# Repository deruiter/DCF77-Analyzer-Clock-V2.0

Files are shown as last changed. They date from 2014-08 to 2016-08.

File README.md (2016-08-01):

 DCF77 Analyzer/Clock v2.0

 This sketch is free software; you can redistribute it and/or
 modify it under the terms of the GNU Lesser General Public
 License as published by the Free Software Foundation; either
 version 2.1 of the License, or (at your option) any later version.
 
 This sketch is distributed in the hope that it will be useful,
 but WITHOUT ANY WARRANTY; without even the implied warranty of
 MERCHANTABILITY or FITNESS FOR A PARTICULAR PURPOSE.  See the GNU
 Lesser General Public License for more details.
 
 You should have received a copy of the GNU Lesser General Public
 License along with this library; if not, write to the Free Software
 Foundation, Inc., 51 Franklin St, Fifth Floor, Boston, MA  02110-1301  USA

 This C++ code is far from optimized because I myself am an Arduino and C++ novice.
 But even after learning some more now, I want to keep the code simpel and readable.
 That is why I maybe over-documented the code to help understand what's going on.

 Erik de Ruiter
 2014-2016

 May 2014 First version
 March 2016 - big overhaul...
 July 2016 - Start with building the v2.0 Clock and adapting the sketch

 Version 2.0 - August 2016
 - This sketch is adapted for my 2.0 version of the DCF/Analyzer Clock. It used the Arduino MEGA and the DCF Superfilter
   by default and to drive the many seperate LED's I now use the ports of an Arduino Mega instead of a Maxim 7219 chip. 
   This is because driving LED's with many different Voltage/Current specs is problematic with the Maxim chip. 
   Lighting additional LED's for expample will influence (dim) the LED's already on. As I'm not an electronics engineer
   my only solution was to use the extra ports of the Arduino Mega. Ofcourse you can use transistors or extra chips to
   drive the LED's but for me this was the obvious solution.
 - Removed all the code to use Maxim 72xx chips with Common Anode displays

                                                                                                                                                                                                                                                                                                                                                                                                                                                                                                                                                                                                                                                                                                                                                                                                                                                                                                                                                                                                                                                                                                                                                                                                                                                                                                                                                                                                                                                                                                                                                                                                                                                                                                                                                                                                                                                                                                                                                                                                                                                                                                                                                                                                                                                                                                                                                                                                                                                                                                                                                                                                                                                                                                                                                                                                                                                                                                                                                                                                                                                                                                                                                                                                                                                                                                                                                                                                                                                                                                                                                                                                                                                                                                                                                            

 Version 1.72 - May 2016
 - Option: Use a cheap Ebay PIR detector to shut off selectable display's when no activity is detected. 
   The switch off delay can be set by the user to prevent the display shutting of if a person
   is not moving but the display should be on.
 - Now the display Night shut-down can be disabled by making both values 'POWERSAVINGOFFTIME'
   and 'POWERSAVINGONTIME' zero. 
 - Fixed temperature display not shutting off at powersave mode.  
 - errorCounter display did not reset every hour so that's fixed

 Version 1.71
 - User option to reset temperature min/max memory at midnight

 Version 1.7:
 - The resolution of the temperature display is improved: from 0.5 to 0.1 degrees Celsius
   Because of the time the DS18B20 sensor needs to convert the temperature and to keep the code clean, 
   the temperature display is updates once per minute.
 - Parity check routine optimized. 
 - More reliable check for bad DCF data, preventing RTC update with invalid data.
 - EoB error now clears inner LED ring as it should.
 - The DCF OK LED now displays the condition of the DCF signal more reliably. Turns off immediately if an error occurs
   and only turns ON when all 3 parity bits are OK.

 Version 1.6:
 - Changed temperature function to only calculate once per minute. Got strange errors before the change because
   I used a delay of 100ms to give the DS18B20 sensor time to calculate the temperature. But the delay function is
   a very bad idea in most c++ code so I finally got rid of it.

 Version 1.5:
 - Complete overhaul of the scanSignal function and the rest of the code! My first attempt worked but could be improved...
 - The rPW and rPT led's did not work as I intended so that is corrected now.
 - The End of Buffer error check routine does work now as it should.
 - I incorporated a Parity check of the incoming DCF signal. In the signal 3 Parity bits are sent so now these are
   checked and only if all three are OK, the received time information is accepted, the display is updated and the RTC synced.
   if desired, you can attach 3 extra dual-color LED's (Common Cathode) to see if each of the 3 Parity bits are OK or Failed.
 - I made wiring (or changing the wiring) much easier I think by putting all the PIN config in one easy to read table
 - As long as you use 1 DS18B20 temp. sensor, I edited the code so you no longer need to figure out the address of the I2C device.
 - Big clean-up of the code...
 - Powersaving by shutting off the displays (the clock remains functioning as normal)
   can now be configured somewhat easier by editing two variables POWERSAVINGONTIME and POWERSAVINGOFFTIME.
 - changed some variable names:
   - Maxim instances 'lc' and 'lc1' are now MaximCC and MaximCA
   - Display description MaximDcfTime is now DisplayTempWeek 
   - DCF77SOUNDPIN is now BUZZERSWITCHPIN
 - LED/Display test after power up now build in

  Short description:
   
  Power On:
    After power-on, first a LED test is performed. The LED's and displays lite up sequentially to keep the power consumption low.
    Then the clock starts receiving DCF pulses and when a Minute Mark (2 seconds gap) is detected, the Minute Marker LED is lit
    and the buffer counter is reset. The inner LED ring now will show the incoming DCF pulses which are also stored in the buffer.
    At 3 moments during reception of data the parity DCF bits are checked to see if the data is valid.

  Valid data received:
    When, at the end of the minute, after the Minute Mark is detected (BF (Buffer Full) LED is lit), all three parity bits are OK
    ('DCF OK' LED is lit), the buffer information is used to extract time and date information. 
    Then the RTC clock is updated ('RTC Synced' LED is lit) and the inner LED ring information is copied to the outer LED ring. 
    The time, date and week display, day LED, summer/wintertime and leap year LED information is updated with the new time information.

  No valid data:
    When one or more of the parity bits are not OK because of a noisy signal, receiving of DCF information is continued but
    will not be used to update the RTC, display's and LED's. The outer LED ring, 'RTC synced' and 'DCF OK' LED's will be reset. 
    Time, date, week, day LED, summer/wintertime LED and leap year LED are not affected and keep displaying the last received valid values.
    The 'Period Time' and/or 'Period With' error LED's will indicate the error(s) and the error counter display is updated. 
    Every hour, the error display will bet set to zero. 
    The EoB, End of Buffer LED is lit when more DCF pulses are received before the Minute Mark is detected due to a noisy signal.
    (When a minute Mark is detected we should have no more than 58 bits/pulses) 
    After the detection of the Minute Marker, a new cycle is started.
 
  Temperature:
    At the 30 second mark, the temperature display will show the High and Low values of the past period after the last reset.
  
  Chime:
    At the beginning of each hour, the Chime (if connected) will sound. 
    At night time, a time set by the user in the code itself, the chime is disabled.

  Power saving, two options:
    1. NIGHT SHUT OFF
       At times set by the user, the displays are shutt off at night and turned on in the morning.
       Look at the POWERSAVINGOFFTIME and POWERSAVINGONTIME variables. 
       Check the function <turnDisplaysOff> to select which displays you want to shut off at night.
    2. PIR SENSOR
       Connect a PIR sensor and activate the PIR option POWERSAVE_BY_PIR and the the delay at PIR_DELAY_TIME.
       Every time the PIR detector senses movement, a minute counter is reset but if no movement is detected
       longer than the PIR_DELAY_TIME, the displays are shut off. 
       When movement occurs, the displays immediately switch on. 
    Note: as said before, the clock will function normally while the displays are shut off. 
    The only thing is you can't see it... ;)

  DCF beep:
    With a switch, connected to pin BUZZERSWITCHPIN, you can hear the received DCF bits coming in. 
    The tone duration is equivalent to pulse width of the DCF bits, so either 100 or 200 ms.
  
  Miscelleanous:
    When the RTC battery is empty or a connection fault is detected, the RTC Error LED is lit.

 CREDITS:
 I learned a lot from the work of Matthias Dalheimer and Thijs Elenbaas who made their own DCF77 decoders.
 Without their work I would not have known where to start.
 I ended up writing my own code (using bits and pieces of their ideas) so I could understand what is happening...
 My code is far from efficient or advanced but it does work and I know what is going on.
 
 * A big Thank You to Brett Oliver and Joop Tap for pointing out some errors!

 Interesting websites:

 - Brett Oliver         : http://home.btconnect.com/brettoliver1/
 - Joop Tap             : http://www.jooptap.nl
 - Thijs Ellenbaas      : http://thijs.elenbaas.net/2012/04/arduino-dcf77-radio-clock-receiver-hardware-2/
 - Mathias Dalheimer    : https://github.com/roddi/DCF77-Arduino/blob/master/DCF77Servoclock/DCF77.h
 - DCF77 wikipedia      : https://en.wikipedia.org/wiki/DCF77
 - Much more DCF77 info : http://www.picbasic.nl/indexes_uk.htm

 - My Flickr website    : https://www.flickr.com/photos/edr1924/albums
 - My Github website    : https://github.com/deruiter
 - The Instructables website for this clock: soon!

 */

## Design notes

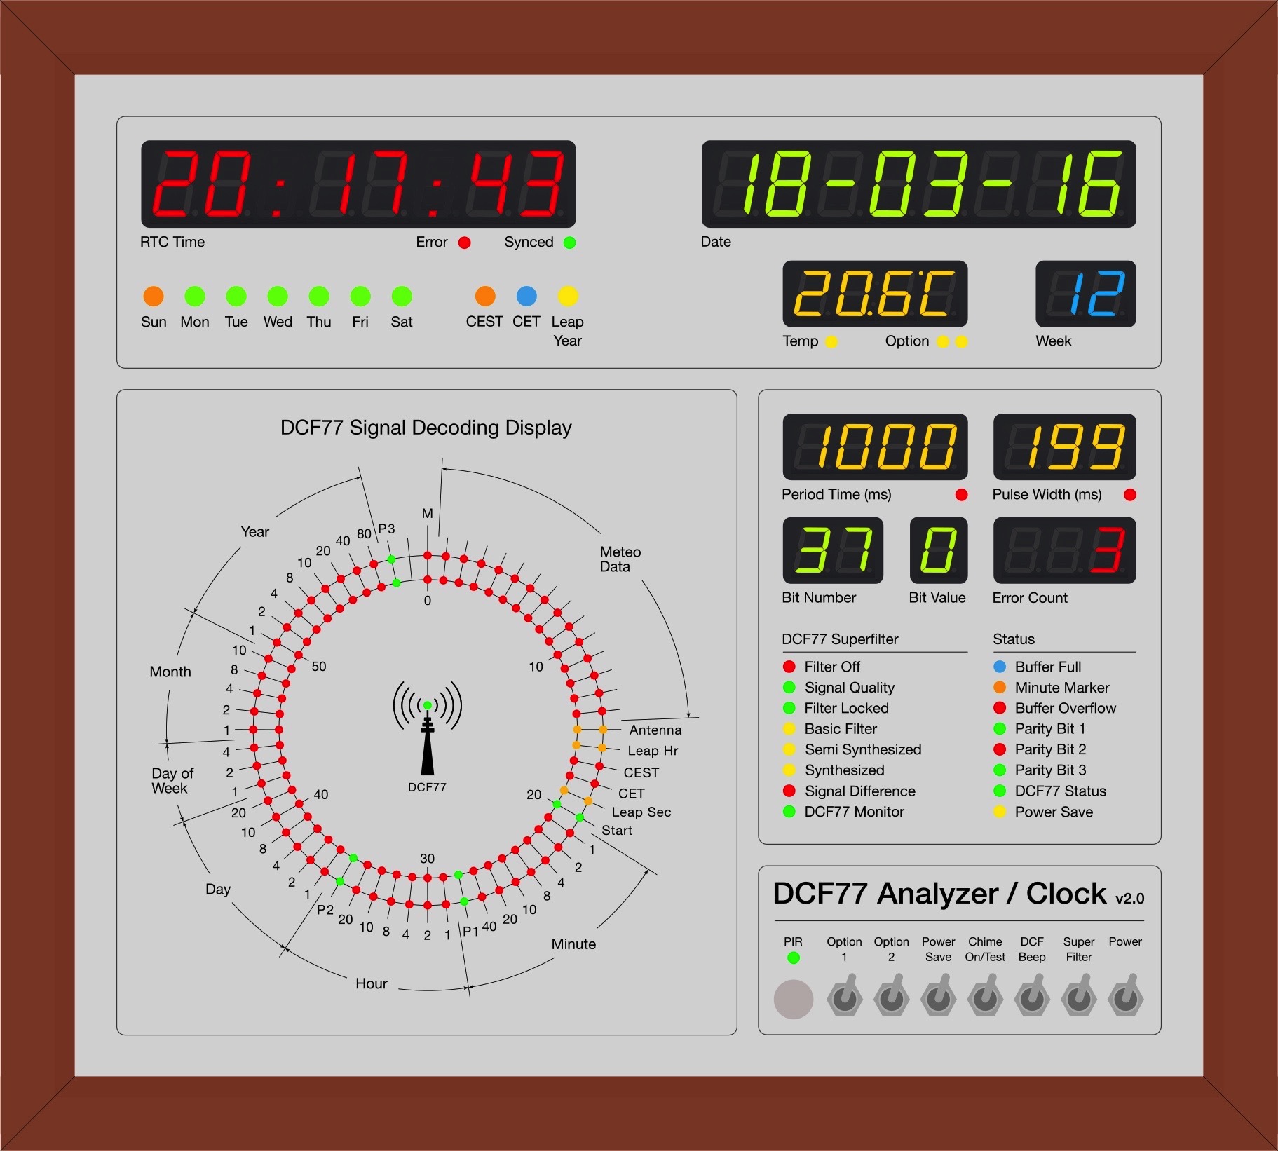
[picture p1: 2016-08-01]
DCF77_Analyzer_Clock_v2_FrontPanel_Preview.jpg

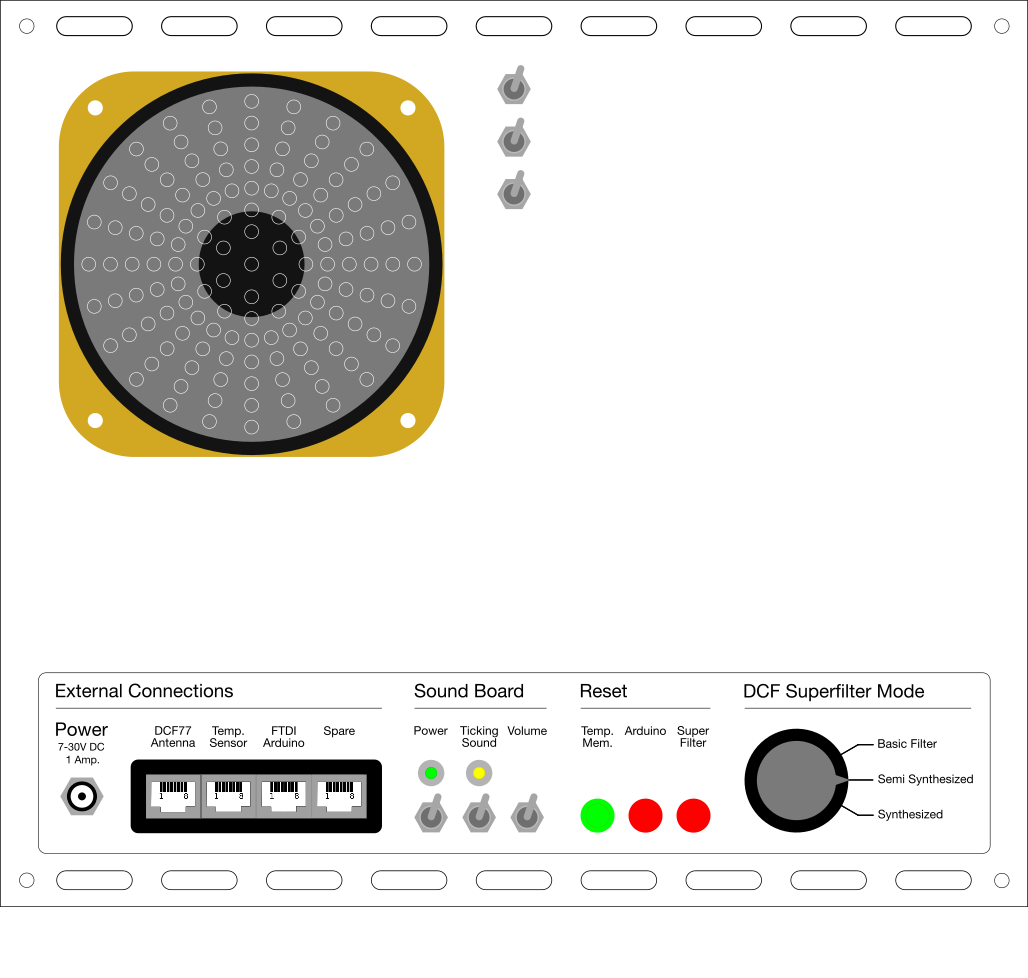
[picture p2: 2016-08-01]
DCF77_Analyzer_Clock_v2_BackPanel_Preview.png

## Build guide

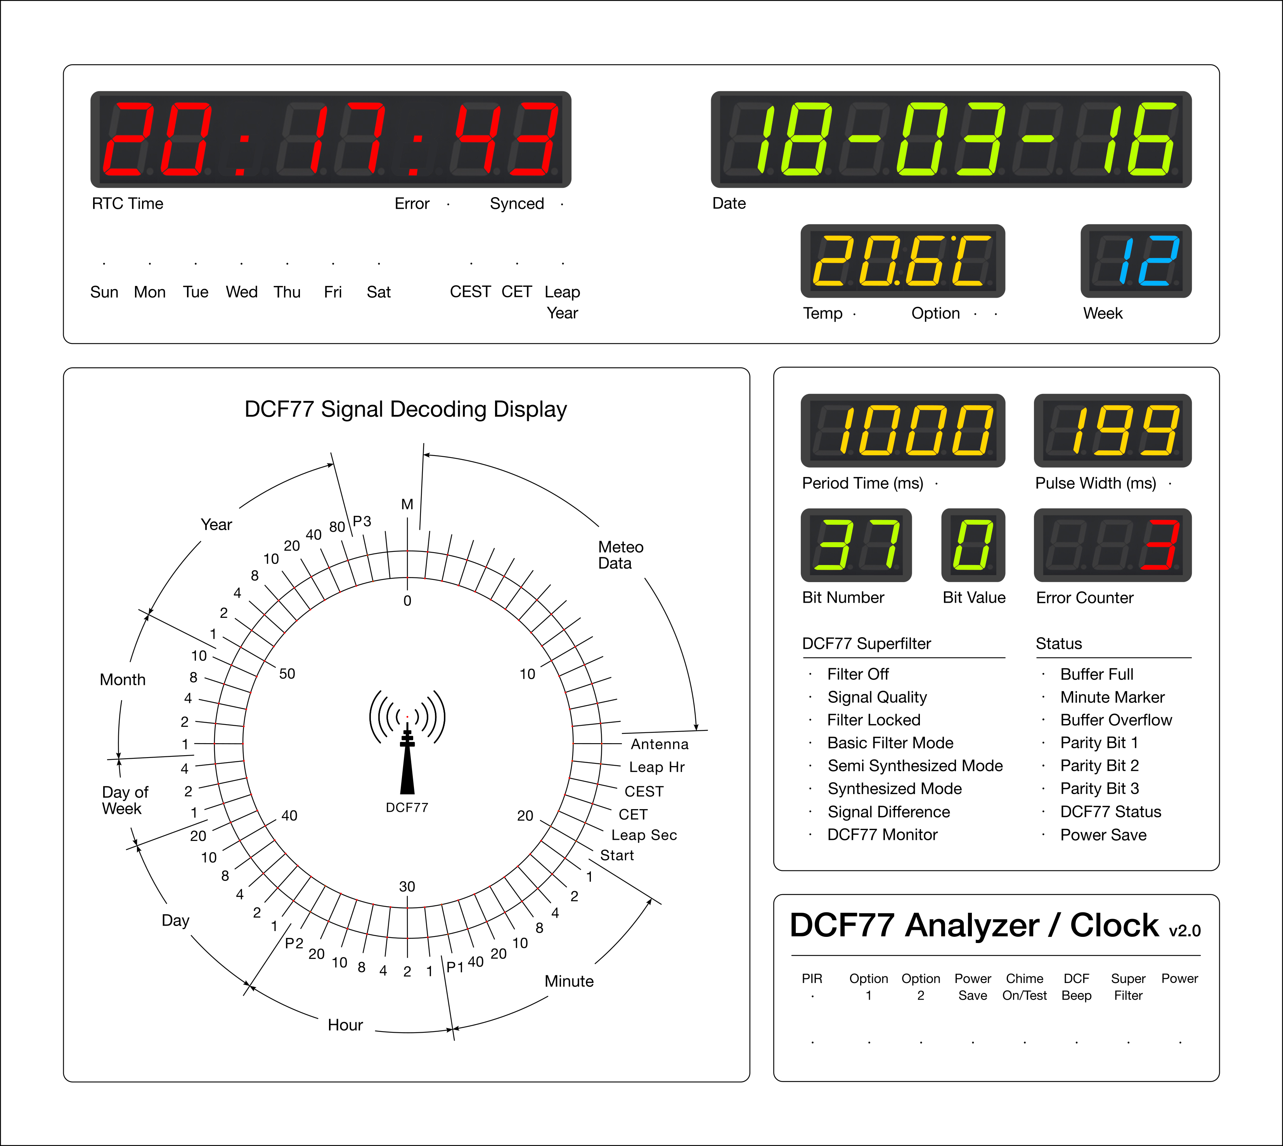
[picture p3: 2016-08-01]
Front_Panel_PrintService_Drawing/DCF77_Analyzer_Clock_v2_FrontPanel_ALUPRINT.jpg

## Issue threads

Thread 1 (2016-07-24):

dcf77 - analyzer - clock

adebruijn, 2016-07-24:
hello mr de ruiter, i am dutch too.

want to make your dcf77 a-clock. very impressive design.

before i start to buy everything by Conrad, is there a kit available ? If there is, it is  easier for me because i am a beginner. I have downloaded al the files. where can i find the code to program the ardueno ?

Greetings

André de Bruijn
Voorhout
The netherlands

deruiter, 2016-07-25:
Hello André, thanks for your interest in my clock.

No, I have no kit for the clock...

On the [Arduino website](http://forum.arduino.cc) you can find all the information you need to program the Arduino.
Reading your question, I think you are better off when you first familiarize yourself with the Arduino platform and the C++ programming language.
This DCF Clock project is not for beginners, I think, although I was myself a beginner when I made it.
BUT I spent hundreds of hours (a year) on the Arduino forum and searching the internet to solve ANY problem I encountered.
Be prepared to do a lot of study yourself, that is the only way to learn and it's very much worth it.

So buy an Arduino kit, and learn to program yourself first so you are able to understand the basics and then invest the money to make bigger projects. You will have a lot of fun learning and discovering the endless possibilities of the Arduino!

adebruijn, 2016-08-12:
hoi erik,

Nog een vraagje, heb jij de benodigde printplaatjes te koop ? ik zag een heel stapeltje op een van je foto's.

scheelt me een heleboel werk. ik kan zelf etsen en heb een uv lamp etc, maar als je ze op de plank hebt ?

groet

André de Bruijn

afmdebruijn@me.com

06-22569679

________________________________
Van: Erik <notifications@github.com>
Verzonden: maandag 25 juli 2016 09:03
Aan: deruiter/DCF77-Analyzer-Clock
CC: adebruijn; State change
Onderwerp: Re: [deruiter/DCF77-Analyzer-Clock] dcf77 - analyzer - clock (#1)

Closed #1<https://github.com/deruiter/DCF77-Analyzer-Clock/issues/1>.

-
You are receiving this because you modified the open/close state.
Reply to this email directly, view it on GitHub<https://github.com/deruiter/DCF77-Analyzer-Clock/issues/1#event-733251882>, or mute the thread<https://github.com/notifications/unsubscribe-auth/ATq4_enD-FUXVqHSL3DVndExIYXXLoBxks5qZHv1gaJpZM4JTlvi>.

deruiter, 2016-08-13:
Hello André,

I like to keep the conversation in English so everyone can understand what's going on.

No, sorry I have no spare PCB's left.
I think etching yourself is not an option in this case because my designs are double sided and the margins are very tiny.

I alway order my pcb's at iTead, and you have them delivered in 2-3 weeks.

Good luck with your build!

adebruijn, 2016-08-21:
hello,

what type of dcf antenna do you use ?

I use de one from conrad, but it does not give me a good signal.

if i run the superfilter program and looking at the serial monitor it seems to be to noisy.

greetings andre

brettoliver, 2016-08-21:
Hi I use this http://www.hkw-shop.de/Empfangstechnik-AM/Antenne-77-5kHz-10x100mm.html?listtype=search&searchparam=dcf77   There is a write up here on Udo's site https://blog.blinkenlight.net/experiments/dcf77/dcf77-receiver-modules/

adebruijn, 2016-09-10:
The 10cm ferriet is producing now a perfect signal.

mr de ruiter, i use the common cathode display's,
the type stated on your display prints. SC39 11 type

what do you mean with the line in your readme file:
Removed all the code to use Maxim 72xx chips with Common Anode displays

do i have to use te Common Anode ?

greetings

André

deruiter, 2016-09-10:
Hello André, Glad you have a good signal now!

In the Clock version 2.0 code, I do not use the [Sparkfun 4 digit display](https://www.sparkfun.com/products/9483) anymore. I used it before because it has a dot at the top left of the last digit so you can use it to display temperature as °C.

The short answer to your Q: you don't need to... ;)

The long answer:
To use Common ANODE displays with the Maxim 72xx chips is not possible because it will only drive common Cathode displays. But someone edited the 'standard' Ledcontrol.h library so with the adapted Ledcontrol.h library (on my github page) you CAN use CA displays by changing the extra BOOLEAN parameter to 'TRUE' when declaring a ledcontrol instance in the code.
(the last parameter as in the example of the 1.72 DCF Clock version of the code:

LedControl MaximCA = LedControl(MAXIMCADATA, MAXIMCACLK, MAXIMCALD, 1, **true**);

Anyway, I now use for the temperature display a common Cathode display and on that display I rotated the right (last) 7 segment display 180 degrees and rewired the dot and 'G' segments to when I want to lit the 'degree dot', I simply activate the 'dot' of that digit.

In the coming days I will update my DCF77 Analyzer / Clock 2.0 page on the [Arduino Project hub](https://create.arduino.cc/projecthub/edr1924/dcf77-analyzer-clock-v2-0-c25404?ref=user&ref_id=96287&offset=0) so you can see how I build the 2.0 clock. I also have a few front panels left if you are interested.

Updating the page is slow because I have limited use of my eyes.

adebruijn, 2016-09-10:
Thanks for your quick and very usefull answer(s)

I made an experimentel setup to check if my self made print's are working. mostly your design, but no bridges. A lot of work wiring the outer cirkel !!!! but all works fine.

only the R SET resistor is difficult to define: with 220ohm the leds are bright on the outer ring,
but when the program starts, and the ring selftest displays the led's back and forth, it does only 30-50%. with 28K the leds are dim, but the selftest works ok all led's go on and off.

what Resistor do you use voor the outer en inner ring ?

i am intererested in one of your front panels !

greetings

andre

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

deruiter, 2016-09-10:
Hi André, For the right resistor value for the LED's, you need to look at the [maxim 72xx datasheet pages 10 and 11](https://datasheets.maximintegrated.com/en/ds/MAX7219-MAX7221.pdf)

I don't know what value I used but I think it was 27K because the most common LED's as a guideline have a Forward Voltage of 2 to 2,5V and a current of 20mA.
In any case, 220 Ohm is way to low! The maxim chip cannot handle the large currents flowing so that's the reason I think some LED's are not lit at all

If the led's are not bright enough **at maximum brightness setting in the code**, then your only option is to use other LED's.  The LED's I used are very bright at the V/I values mentioned. Other LED's I have are very dim in comparison but are cheap.

I don't know yet how to pass my private email address to you so we can arrange the front panel sale but when I do I will let you know.

GvLaere, 2016-09-22:
Hello sir,
Your project is really wonderful! I can understand that this had taken a lot of time!
I'm a beginner and have less experience Arduino. I just make simple projects.
My question is if you have a suggestion where I can find just a clock with DCF77 with only 6 digits 7 segment LED (hours, minutes and seconds). I have huge LED 7 segments display's and I want to make a clock with DCF77. For me it is not simple to extract the right code and sketch out of your project.
Thanks for your help!
Greeting Guido
Oirschot / The Netherlands

deruiter, 2016-09-30:
Hello Guido, thanks for your comments. I suggest using Google to search for another project with DCF77. for example "DCF77 clock arduino" will give you the result you are looking for.

adebruijn, 2016-10-02:
Hello mr de Ruiter,

Your clock design is ready. I made all the prints, had to redesign them though, and all is working. only some trouble with the PIR. I had bought the Conrad PIR A27/360. This was not working directly with your design. So for everybody who also want to make this nice clock from mr de ruiter, here my design for an interface to connect the PIR to the PIR port D3 on mr de Ruiters DCF Analalyzer.

PIRprint.PDF is the schematic
In the ZIP the Eagle files

Greetings André

[pirprint.pdf](https://github.com/deruiter/DCF77-Analyzer-Clock-V2.0/files/504849/pirprint.pdf)

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

[pirprint.zip](https://github.com/deruiter/DCF77-Analyzer-Clock-V2.0/files/504850/pirprint.zip)

adebruijn, 2016-10-13:
strange behavior .....

Do you recognize this problem mr de de ruiter ?

the 6th display print with the time display, does not work with the max7221 but only a max 7219.
when I change the 7221 with another chip out of a working first or second etc board no change. if I change the board to fourth or any other position in the chain it works with the 7221. I do not understand. Any ideas ?

so  in pos 6 (last in chain, nr 7) only with a 7219 the display work.

if I switch on, all display's also nr 6 with 7221 lights up. then the display test follows, nr 6 doesn't work. replacing with a 7219 no problems.

al is working and now I start to make the case. i have a 3d printer, and making a front with all the holes is very easy !!! over the white ABS printed frontplate i use a transparent printer sheet to make the decals. after this a thin 2mm glass plate finishes the front plate.

This is the plan, if it works i put in a few pics.

adebruijn, 2016-10-15:
hello mr de Ruiter,

I have noticed someting, the pulse width when in super filter mode and only in the meteo range,
is the pulse width 177-183 when low (0), and 199-201 when high. (1)

this gives as result if I do not edit the value 170 to 185 in

    // process DCF bits
    //--------------------------------------------------------------------------------
    // distinguish between long and short pulses
    if (trailingEdge - leadingEdge < 185) //org 170
    {

that all the bits from 2- 15 are registred high (1).

if I switch the filter off, the bits are low 99-101 en high 199-201 in the whole range from 1-58.

???????

deruiter, 2016-10-15:
Hello André,

Q1: I only use the Maxim 7221 chips because of the lower MRI.  I do not recognize the problem you have?  Do you use genuine versions of the Maxims?  I did use Chinese chips first but not anymore...

Q2: The superfilter has 3 modes, maybe you can use one of the other modes? I think it was in BASIC mode, the meteo bits are left alone and passed through "as-is"
That said, I did not experience the problem myself. So I cannot replicate the problem and help you solve it.  For detailed support concerning the Superfilter, I think it's better to ask the maker Udo Klein.

I'm sorry I cannot help you! Hopefully you are able to get around these issues...

Looking forward to see your 3D printed front panel design!

adebruijn, 2016-10-16:
hello mr de Ruiter thanks for your answer. I replaced all the MAX7221. One was faulty I think and did not let nr 7 get trough. But the funny thing, it let the 7219 in nr 7 through anyway !.

You can check the faulty pulse width in bit 1-14, put superfilter OFF, and look at the pulse width numbers, the bits are low 99-101 en high 199-201 in the whole range from 1-58. (if you have a good reception of the singal offcourse) BUT, with superfilter in 1/2/3 mode it gives a pulse width 177-183 when low (becomes 1), and 199-201 when high. (1).

I put a sketchup 3D sketch picture in, you can see all the islands where all the print plates can be put.

Greetings André
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

adebruijn, 2016-10-16:
![Uploading dcf77v5a.jpg…]()

adebruijn, 2016-10-25:
ready !!! only the decal sheet for the front en the glassplate.
then All on top of a nice box.

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

deruiter, 2016-10-25:
Wow, this is quite a feat of engineering... Certainly it looks a lot neater than the wiring in my clock ;)
This has been a lot of work, making all those custom pcb's.

Thanks for the foto's, looking forward to the finished clock in it's casing!

adebruijn, 2016-11-09:
coming right up !!!! thanks for your nice sketch'es and scematic !!!

adebruijn, 2021-09-18:
just an update which had to be much earlier....

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
.

adebruijn, 2021-09-18:
with new designed/pcb for bigger displays for the date and time

Closed 2021-09-18.

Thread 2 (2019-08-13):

lapYear evaluation is missing an equal sign

tobozo, 2019-08-13:
Hello Mr De Ruiter

your design is so good I'm porting it to a small TFT display, while doing that I noticed a tiny typo in the source code :

https://github.com/deruiter/DCF77-Analyzer-Clock-V2.0/blob/fe2abf0495169203b5e177e568e68616adc71c21/Arduino%20Sketches/DCF77_Analyzer_Clock_2_0_Main_sketch/DCF77_Ana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

should read:

```c
    if (leapYear == 1)
```

deruiter, 2019-08-13:
wow, thank you very much!  I forgot to correct this error, sorry about that...!
I don't know how to give you credit here but many thanks...
Erik

tobozo, 2019-08-13:
Thanks to you I had much fun working on your code to get it working, now I'm the one giving you credits here : https://youtu.be/V3Gqdkv7T00

Would that be okay if I published the modified code?

If so, please let me know if you prefer a standalone/detached project to a fork attached to your repository.

I can also validate the credits/license with you before making it public.

tobozo, 2019-08-21:
hey ^^ I just published the TFT version here https://github.com/tobozo/esp32-DCF77_Analyzer_Clock

please let me know if you need me to make modifications (license, credits), I've tried my best to put every bits but I'm only human :-)

deruiter, 2019-08-21:
Hello Tobozo,
Sorry, I forgot to reply to your previous email...
WOW what an amazig clock you made!!!
Thank you for letting me know, no need for modifications, thanks for the credits although it's all open source.
Now i want to make your version also! ;)
I have to look at your code to learn new things... The DCF Clock was my first Arduino project so it has lots to be desired but it at least did work...
Thanks again!
Erik

tobozo, 2019-08-21:
I've added the support for the weather, still very basic though.

deruiter, 2019-08-21:
Hello Tobozo,
Sorry, I forgot to reply to your previous email...
WOW what an amazig clock you made!!!
Thank you for letting me know, no need for modifications, thanks for the credits although it's all open source.
Now i want to make your version also! ;)
I have to look at your code to learn new things... The DCF Clock was my first Arduino project so it has lots to be desired but it at least did work...
Thanks again!
Erik

> I've added the support for the weather, still very basic though.

This is great as it is...!
If you are OK with it, I can add your version of the clock on my Hackster project page?

tobozo, 2019-08-21:
of course I'm ok with it :-)

I'm playing with the UI anyway, I'm not sure yet what will happen when the app will load in a M5Stack or Odroid-Go but 320*240 offers much more space, and this could be used to display the weather data in a more comprehensive way.

deruiter, 2019-08-21:
Done, added your clock URL at the end of the page under 'Take a look' header...
Great work!

Closed 2019-08-21.

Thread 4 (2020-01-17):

Switches without connections ?

Bertusdejong, 2020-01-17:
Hi Erik,
Great project. I just -nearly- finished building it. I came across some issues:
Unable to find how to connect the Option 1and Option 2 Switches.
Can't find either how to connect the power save switch (from the code I see it has to be connected to pin 6 . But the code itself doesnot show any readout of this pin).
Hope you can help me out on this!
Thanks in advance

deruiter, 2020-01-18:
See my email, issue is fixed...
new code on my Hackster.io/edr1924 page...

Closed 2020-01-18.

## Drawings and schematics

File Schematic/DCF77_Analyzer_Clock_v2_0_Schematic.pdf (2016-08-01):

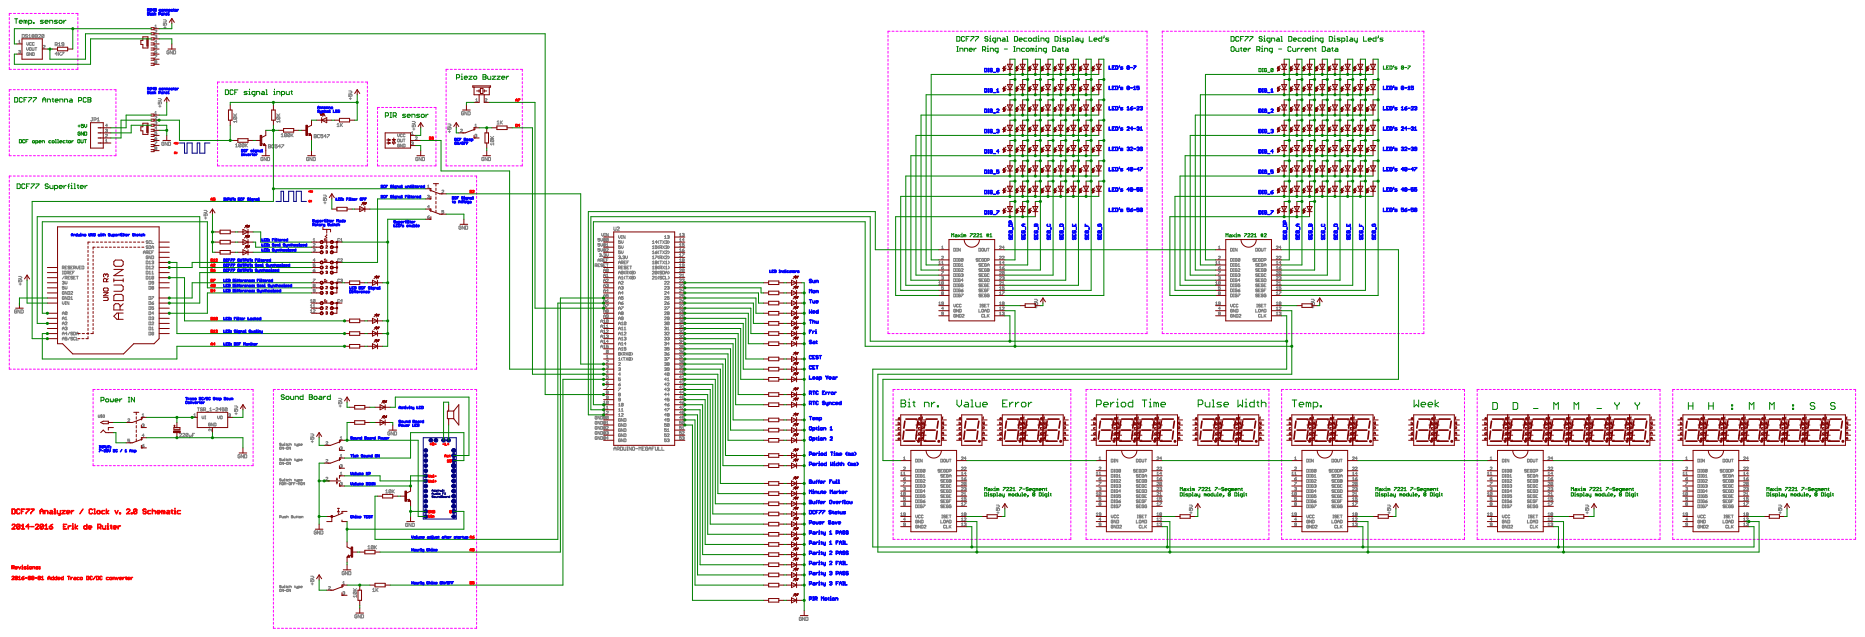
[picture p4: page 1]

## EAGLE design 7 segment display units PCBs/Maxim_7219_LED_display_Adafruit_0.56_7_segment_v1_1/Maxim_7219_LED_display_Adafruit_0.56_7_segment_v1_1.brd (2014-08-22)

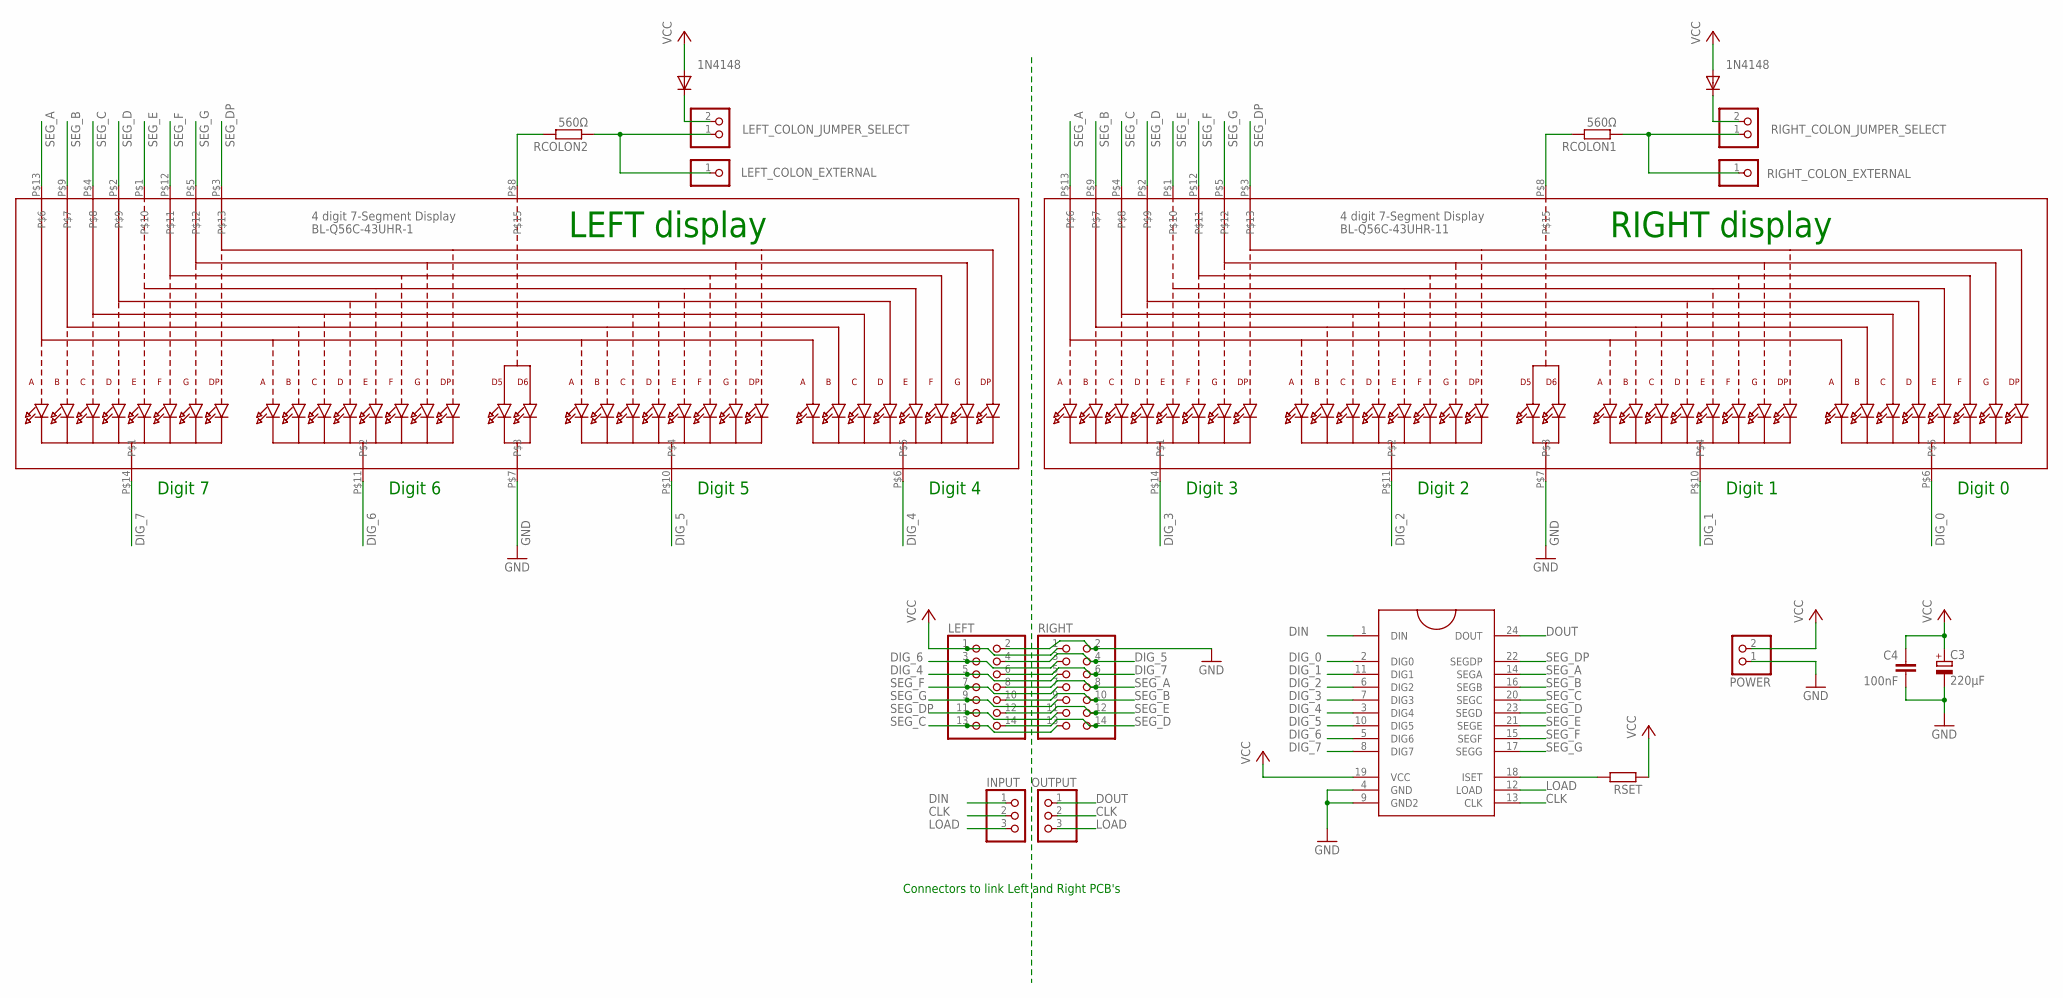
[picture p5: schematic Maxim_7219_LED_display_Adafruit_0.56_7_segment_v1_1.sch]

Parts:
BL-Q56C-43UHR-1, BL-Q56C-43UHR-11: 4 digit 7-Segment Display; SEGMENT-BL-Q56C43
C3: 220µF; E5-10,5
C4: 100nF; C050-025X075
D2, D3: 1N4148; DO35-7
INPUT: PINHD-1X3; 1X03
LEFT: PINHD-2X7; 2X07
LEFT_COLON_EXTERNAL: M01SMDNS; 1X01
LEFT_COLON_JUMPER_SELECT: PINHD-1X2; 1X02
OUTPUT: PINHD-1X3; 1X03
POWER: PINHD-1X2; 1X02
RCOLON1, RCOLON2: 560Ω; 0207/10
RIGHT: PINHD-2X7; 2X07
RIGHT_COLON_EXTERNAL: PINHD-1X1; 1X01
RIGHT_COLON_JUMPER_SELECT: PINHD-1X2; 1X02
RSET: R-EU_0207/2V; 0207/2V
U$3: MAX7219DIP; DIL24

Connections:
CLK: INPUT.2, OUTPUT.2, U$3.13 (CLK)
DIG_0: BL-Q56C-43UHR-11.P$6, U$3.2 (DIG0)
DIG_1: BL-Q56C-43UHR-11.P$10, U$3.11 (DIG1)
DIG_2: BL-Q56C-43UHR-11.P$11, U$3.6 (DIG2)
DIG_3: BL-Q56C-43UHR-11.P$14, U$3.7 (DIG3)
DIG_4: BL-Q56C-43UHR-1.P$6, LEFT.5, RIGHT.5, U$3.3 (DIG4)
DIG_5: BL-Q56C-43UHR-1.P$10, LEFT.4, RIGHT.4, U$3.10 (DIG5)
DIG_6: BL-Q56C-43UHR-1.P$11, LEFT.3, RIGHT.3, U$3.5 (DIG6)
DIG_7: BL-Q56C-43UHR-1.P$14, LEFT.6, RIGHT.6, U$3.8 (DIG7)
DIN: INPUT.1, U$3.1 (DIN)
DOUT: OUTPUT.1, U$3.24 (DOUT)
GND: BL-Q56C-43UHR-1.P$7, BL-Q56C-43UHR-11.P$7, C3.-, C4.2, LEFT.2, POWER.1, RIGHT.2, U$3.4 (GND), U$3.9 (GND2)
LOAD: INPUT.3, OUTPUT.3, U$3.12 (LOAD)
unnamed: D2.C, LEFT_COLON_JUMPER_SELECT.2
unnamed: LEFT_COLON_EXTERNAL.1, LEFT_COLON_JUMPER_SELECT.1, RCOLON2.1
unnamed: BL-Q56C-43UHR-1.P$8, RCOLON2.2
unnamed: BL-Q56C-43UHR-11.P$8, RCOLON1.2
unnamed: D3.C, RIGHT_COLON_JUMPER_SELECT.2
unnamed: RCOLON1.1, RIGHT_COLON_EXTERNAL.1, RIGHT_COLON_JUMPER_SELECT.1
unnamed: RSET.2, U$3.18 (ISET)
SEG_A: BL-Q56C-43UHR-1.P$13, BL-Q56C-43UHR-11.P$13, LEFT.8, RIGHT.8, U$3.14 (SEGA)
SEG_B: BL-Q56C-43UHR-1.P$9, BL-Q56C-43UHR-11.P$9, LEFT.10, RIGHT.10, U$3.16 (SEGB)
SEG_C: BL-Q56C-43UHR-1.P$4, BL-Q56C-43UHR-11.P$4, LEFT.13, RIGHT.13, U$3.20 (SEGC)
SEG_D: BL-Q56C-43UHR-1.P$2, BL-Q56C-43UHR-11.P$2, LEFT.14, RIGHT.14, U$3.23 (SEGD)
SEG_DP: BL-Q56C-43UHR-1.P$3, BL-Q56C-43UHR-11.P$3, LEFT.11, RIGHT.11, U$3.22 (SEGDP)
SEG_E: BL-Q56C-43UHR-1.P$1, BL-Q56C-43UHR-11.P$1, LEFT.12, RIGHT.12, U$3.21 (SEGE)
SEG_F: BL-Q56C-43UHR-1.P$12, BL-Q56C-43UHR-11.P$12, LEFT.7, RIGHT.7, U$3.15 (SEGF)
SEG_G: BL-Q56C-43UHR-1.P$5, BL-Q56C-43UHR-11.P$5, LEFT.9, RIGHT.9, U$3.17 (SEGG)
VCC: C3.+, C4.1, D2.A, D3.A, LEFT.1, POWER.2, RIGHT.1, RSET.1, U$3.19 (VCC)

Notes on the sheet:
LEFT display
RIGHT display
Connectors to link Left and Right PCB's
Digit 0
Digit 1
Digit 2
Digit 3
Digit 4
Digit 5
Digit 6
Digit 7

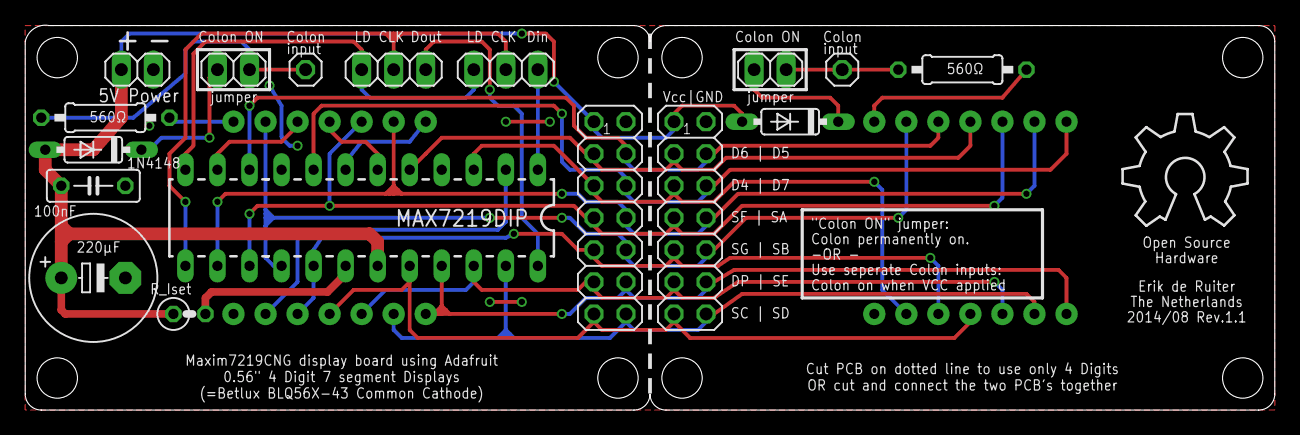
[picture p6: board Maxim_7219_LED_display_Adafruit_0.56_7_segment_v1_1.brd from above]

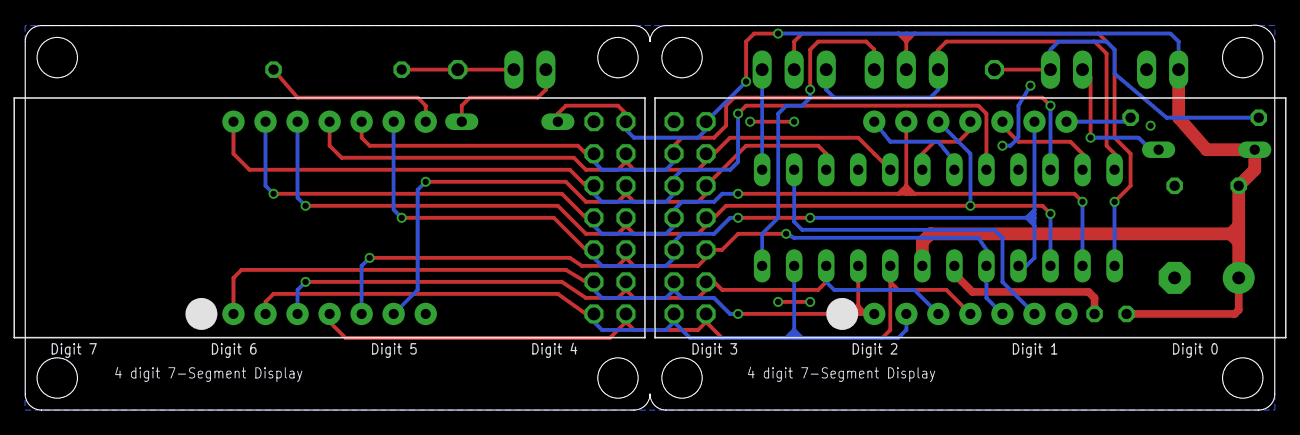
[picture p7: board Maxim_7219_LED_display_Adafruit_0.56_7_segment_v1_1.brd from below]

Board: 2 copper layers, 99.1 x 30.5 mm, 20 parts (2 on the bottom side), 29 nets.

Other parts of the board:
U$2: OSHW_8X350_NOTEXT

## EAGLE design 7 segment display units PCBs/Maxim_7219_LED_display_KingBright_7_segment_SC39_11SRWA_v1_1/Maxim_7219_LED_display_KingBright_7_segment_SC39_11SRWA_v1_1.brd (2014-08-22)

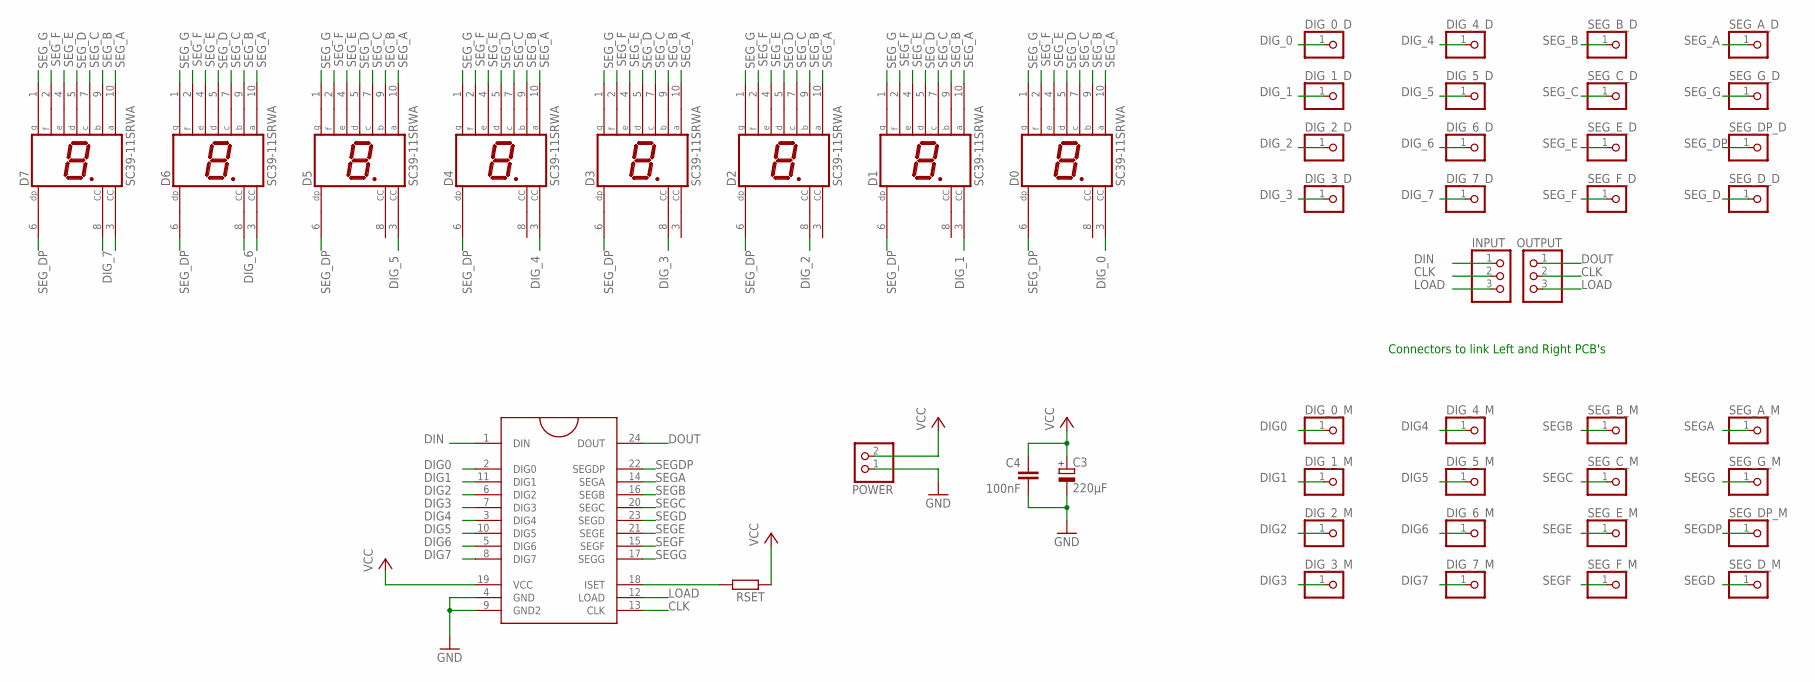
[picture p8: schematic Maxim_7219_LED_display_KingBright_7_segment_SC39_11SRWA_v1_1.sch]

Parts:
C3: 220µF; E3,5-8
C4: 100nF; C050-025X075
D0, D1, D2, D3, D4, D5, D6, D7: SC39-11SRWA; HDSP-E
DIG_0_D, DIG_0_M, DIG_1_D, DIG_1_M, DIG_2_D, DIG_2_M, DIG_3_D, DIG_3_M, DIG_4_D, DIG_4_M, DIG_5_D, DIG_5_M, DIG_6_D, DIG_6_M, DIG_7_D, DIG_7_M: PINHD-1X1; 1X01
INPUT: PINHD-1X3; 1X03
OUTPUT: PINHD-1X3; 1X03
POWER: PINHD-1X2; 1X02
RSET: R-EU_0207/10; 0207/10
SEG_A_D: PINHD-1X1; 1X01
SEG_A_M: PINHD-1X1; 1X01
SEG_B_D: PINHD-1X1; 1X01
SEG_B_M: PINHD-1X1; 1X01
SEG_C_D: PINHD-1X1; 1X01
SEG_C_M: PINHD-1X1; 1X01
SEG_DP_D: PINHD-1X1; 1X01
SEG_DP_M: PINHD-1X1; 1X01
SEG_D_D: PINHD-1X1; 1X01
SEG_D_M: PINHD-1X1; 1X01
SEG_E_D: PINHD-1X1; 1X01
SEG_E_M: PINHD-1X1; 1X01
SEG_F_D: PINHD-1X1; 1X01
SEG_F_M: PINHD-1X1; 1X01
SEG_G_D: PINHD-1X1; 1X01
SEG_G_M: PINHD-1X1; 1X01
U$3: MAX7219DIP; DIL24

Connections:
CLK: INPUT.2, OUTPUT.2, U$3.13 (CLK)
DIG0: DIG_0_M.1, U$3.2 (DIG0)
DIG1: DIG_1_M.1, U$3.11 (DIG1)
DIG2: DIG_2_M.1, U$3.6 (DIG2)
DIG3: DIG_3_M.1, U$3.7 (DIG3)
DIG4: DIG_4_M.1, U$3.3 (DIG4)
DIG5: DIG_5_M.1, U$3.10 (DIG5)
DIG6: DIG_6_M.1, U$3.5 (DIG6)
DIG7: DIG_7_M.1, U$3.8 (DIG7)
DIG_0: D0.3 (CC), DIG_0_D.1
DIG_1: D1.3 (CC), DIG_1_D.1
DIG_2: D2.8 (CC), DIG_2_D.1
DIG_3: D3.8 (CC), DIG_3_D.1
DIG_4: D4.3 (CC), DIG_4_D.1
DIG_5: D5.3 (CC), DIG_5_D.1
DIG_6: D6.8 (CC), DIG_6_D.1
DIG_7: D7.8 (CC), DIG_7_D.1
DIN: INPUT.1, U$3.1 (DIN)
DOUT: OUTPUT.1, U$3.24 (DOUT)
GND: C3.-, C4.2, POWER.1, U$3.4 (GND), U$3.9 (GND2)
LOAD: INPUT.3, OUTPUT.3, U$3.12 (LOAD)
unnamed: RSET.2, U$3.18 (ISET)
SEGA: SEG_A_M.1, U$3.14 (SEGA)
SEGB: SEG_B_M.1, U$3.16 (SEGB)
SEGC: SEG_C_M.1, U$3.20 (SEGC)
SEGD: SEG_D_M.1, U$3.23 (SEGD)
SEGDP: SEG_DP_M.1, U$3.22 (SEGDP)
SEGE: SEG_E_M.1, U$3.21 (SEGE)
SEGF: SEG_F_M.1, U$3.15 (SEGF)
SEGG: SEG_G_M.1, U$3.17 (SEGG)
SEG_A: D0.10 (A), D1.10 (A), D2.10 (A), D3.10 (A), D4.10 (A), D5.10 (A), D6.10 (A), D7.10 (A), SEG_A_D.1
SEG_B: D0.9 (B), D1.9 (B), D2.9 (B), D3.9 (B), D4.9 (B), D5.9 (B), D6.9 (B), D7.9 (B), SEG_B_D.1
SEG_C: D0.7 (C), D1.7 (C), D2.7 (C), D3.7 (C), D4.7 (C), D5.7 (C), D6.7 (C), D7.7 (C), SEG_C_D.1
SEG_D: D0.5 (D), D1.5 (D), D2.5 (D), D3.5 (D), D4.5 (D), D5.5 (D), D6.5 (D), D7.5 (D), SEG_D_D.1
SEG_DP: D0.6 (DP), D1.6 (DP), D2.6 (DP), D3.6 (DP), D4.6 (DP), D5.6 (DP), D6.6 (DP), D7.6 (DP), SEG_DP_D.1
SEG_E: D0.4 (E), D1.4 (E), D2.4 (E), D3.4 (E), D4.4 (E), D5.4 (E), D6.4 (E), D7.4 (E), SEG_E_D.1
SEG_F: D0.2 (F), D1.2 (F), D2.2 (F), D3.2 (F), D4.2 (F), D5.2 (F), D6.2 (F), D7.2 (F), SEG_F_D.1
SEG_G: D0.1 (G), D1.1 (G), D2.1 (G), D3.1 (G), D4.1 (G), D5.1 (G), D6.1 (G), D7.1 (G), SEG_G_D.1
VCC: C3.+, C4.1, POWER.2, RSET.1, U$3.19 (VCC)

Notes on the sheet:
Connectors to link Left and Right PCB's

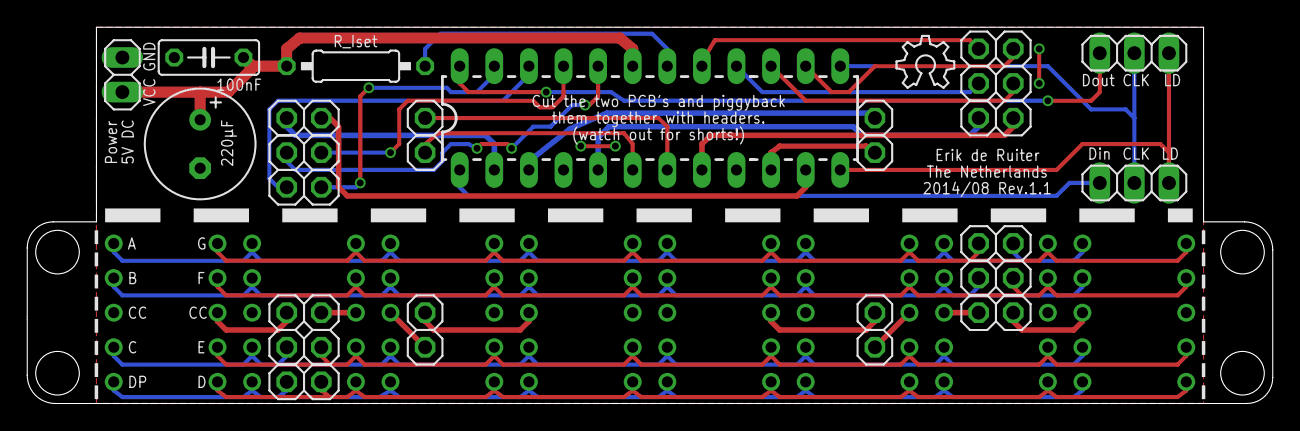
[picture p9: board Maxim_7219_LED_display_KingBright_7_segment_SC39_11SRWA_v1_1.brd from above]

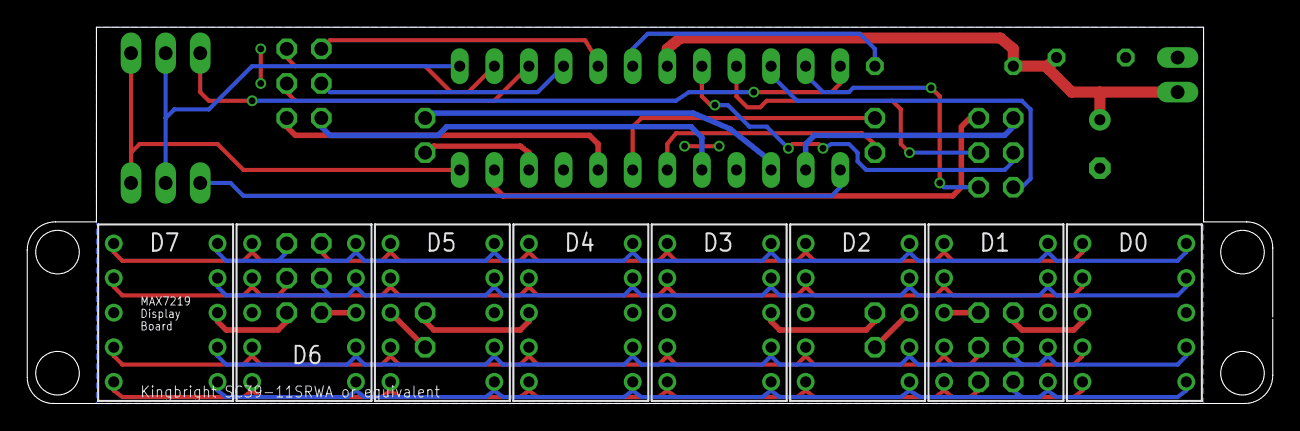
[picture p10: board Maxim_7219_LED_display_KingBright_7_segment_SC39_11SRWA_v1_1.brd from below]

Board: 2 copper layers, 91.4 x 27.6 mm, 48 parts (8 on the bottom side), 39 nets.

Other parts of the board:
U$2: OSHW_6X150_NOTEXT

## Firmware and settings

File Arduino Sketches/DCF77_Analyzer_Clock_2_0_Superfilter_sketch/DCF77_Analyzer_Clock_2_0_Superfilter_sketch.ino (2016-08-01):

//
//  This is the Superfilter sketch I use with the DCF Analyzer/Clock 2.0 
//  Udo Klein did an amazing job with this filter
//
//  Erik de Ruiter

/*
    Arduino Uno pin connections I used for the DCF Analyzer Clock

    DCF input ................. A5 (19)  = dcf77_sample_pin
    Output DCF Filtered ....... 12       = dcf77_filtered_pin
    Output DCF Semi Synthesized A2 (16)  = dcf77_semi_synthesized_pin
    Output DCF Synthesized ....  6       = dcf77_synthesized_pin
    LED DCF output filtered ... A4 (18)  = dcf77_monitor_pin                    = DCF Monitor LED
    LED 1 Hz pulse ............ 10       = dcf77_second_pulse_pin               = Filter Locked LED
    LED DCF OK ................ 13       = dcf77_signal_good_indicator_pin      = Signal Quality LED
    LED Difference Filtered ...  7       = dcf77_filter_diff_pin            \      
    LED Difference Semi Synth.. A0       = dcf77_semi_synthesized_diff_pin   -> = Signal Difference LED
    LED Difference Synthesized   4       = dcf77_synthesized_diff_pin       /
*/
    
//
//  www.blinkenlight.net
//
//  Copyright 2014, 2015 Udo Klein
//
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
#include <dcf77.h>
/*
const uint8_t pon_pin  = 51; // connect pon to ground !!!
const uint8_t data_pin = 19;
const uint8_t gnd_pin  = 51;
const uint8_t vcc_pin  = 49;
*/

const uint8_t dcf77_analog_samples = false;
const uint8_t dcf77_analog_sample_pin = 5;
const uint8_t dcf77_sample_pin = 19; // A5
const uint8_t dcf77_inverted_samples = 0;
#if defined(__AVR__)
#define ledpin(led) (led)
#else
#define ledpin(led) (led<14? led: led+(54-14))
#endif

const uint8_t dcf77_monitor_pin = ledpin(18); // A4

const bool provide_filtered_output = true;
const uint8_t dcf77_filtered_pin          = ledpin(12);
const uint8_t dcf77_inverted_filtered_pin = ledpin(11);
const uint8_t dcf77_filter_diff_pin       = ledpin(7);

const bool provide_semi_synthesized_output = true;
const uint8_t dcf77_semi_synthesized_pin          = ledpin(16);
const uint8_t dcf77_inverted_semi_synthesized_pin = ledpin(15);
const uint8_t dcf77_semi_synthesized_diff_pin     = ledpin(14);

const bool provide_synthesized_output = true;
const uint8_t dcf77_synthesized_pin          = ledpin(6);
const uint8_t dcf77_inverted_synthesized_pin = ledpin(5);
const uint8_t dcf77_synthesized_diff_pin     = ledpin(4);

const uint8_t dcf77_second_pulse_pin = ledpin(10);


const uint8_t dcf77_signal_good_indicator_pin = ledpin(13);

volatile uint16_t ms_counter = 0;
volatile Internal::DCF77::tick_t tick = Internal::DCF77::undefined;


template <bool enable, uint8_t threshold,
          uint8_t filtered_pin, uint8_t inverted_filtered_pin, uint8_t diff_pin>
void set_output(uint8_t clock_state, uint8_t sampled_data, uint8_t synthesized_signal)
{
    if (enable) {
        const uint8_t filtered_output = clock_state < threshold? sampled_data: synthesized_signal;
        digitalWrite(filtered_pin, filtered_output);
        digitalWrite(inverted_filtered_pin, !filtered_output);
        digitalWrite(diff_pin, filtered_output ^ sampled_data);
    }
}

namespace {
    struct Scope {
        static const uint16_t samples_per_second = 1000;
        static const uint8_t bins                = 100;
        static const uint8_t samples_per_bin     = samples_per_second / bins;

        volatile uint8_t gbin[bins];
        volatile boolean samples_pending = false;
        volatile uint32_t count = 0;

        void process_one_sample(const uint8_t sample) {
            static uint8_t sbin[bins];

            static uint16_t ticks = 999;  // first pass will init the bins
            ++ticks;

            if (ticks == 1000) {
                ticks = 0;
                memcpy((void *)gbin, sbin, bins);
                memset(sbin, 0, bins);
                samples_pending = true;
                ++count;
            }
            sbin[ticks/samples_per_bin] += sample;
        }

        void print() {
            uint8_t lbin[bins];

            if (samples_pending) {
                noInterrupts();
                memcpy(lbin, (void *)gbin, bins);
                samples_pending = false;
                interrupts();

                // ensure the count values will be aligned to the right
                for (int32_t val=count; val < 100000000; val *= 10) {
                    Serial.print(' ');
                }
                Serial.print((int32_t)count);
                Serial.print(", ");
                for (uint8_t bin=0; bin<bins; ++bin) {
                    switch (lbin[bin]) {
                        case  0: Serial.print(bin%10? '-': '+'); break;
                        case 10: Serial.print('X');              break;
                        default: Serial.print(lbin[bin]);
                    }
                }
                Serial.println();
            }
        }
    };
}

Scope scope_1;
Scope scope_2;
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

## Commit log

2014-08-22 Added Eagle files
    [Maxim 7219 LED Display v1.1.brd, Maxim 7219 LED Display v1.1.sch]
2014-08-22 moved to folder
    [Maxim 7219 LED Display v1.1.brd, Maxim 7219 LED Display v1.1.sch]
2014-08-22 Revert "moved to folder"
    This reverts commit 2a864635d2108374a6d6668000cdb38c7414912c.
    [Maxim 7219 LED Display v1.1.brd, Maxim 7219 LED Display v1.1.sch]
2014-08-22 Display Board Eagle files
    [Maxim 7219 LED Display v1.1.brd, Maxim 7219 LED Display v1.1.sch]
2014-08-22 Eagle Cad Display Board
    [Maxim 7219 LED display - KingBright 7 segment SC39-11SRWA v.1.1.brd, Maxim 7219 LED display - KingBright 7 segment SC39-11SRWA v.1.1.sch, Maxim 7219 LED displa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]
2014-08-22 MODIFIED Ledcontrol library
    With this library, you can use Common ANODE displays if you want with
    the Maxim 72xx chips!
2015-03-22 Schematic added, finally!
2015-03-23 Added other schematic versions
2016-05-21 UPDATE
    addes some useful options (I think…)
2019-08-13 fixed leap year error
    [DCF77_Analyzer_Clock_2_0_Main_sketch.ino]

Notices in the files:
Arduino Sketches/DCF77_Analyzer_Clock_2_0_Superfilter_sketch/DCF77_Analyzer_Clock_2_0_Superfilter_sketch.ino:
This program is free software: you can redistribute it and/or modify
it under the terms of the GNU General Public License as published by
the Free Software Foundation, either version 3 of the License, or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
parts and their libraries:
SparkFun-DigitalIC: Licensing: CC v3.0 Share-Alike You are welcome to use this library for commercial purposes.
